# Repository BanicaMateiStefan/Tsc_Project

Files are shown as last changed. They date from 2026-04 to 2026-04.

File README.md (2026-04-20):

# Tsc_Project

## Descriere scurta
    Proiectul are ca obiectiv realizarea designului hardware complet pentru un smartwatch open-source numit InkTime, incluzand schema electrica,PCB-ul, integrarea in carcasa, fisierele de productie si documentatia necesara.

## Diagrama Bloc

Arhitectura hardware este centrata pe microcontrolerul nRF52840, bazat pe ARM Cortex-M4F, care coordoneaza toate perifericele sistemului. Acesta comunica cu:

E-Paper Display-ul, pentru afisarea informatiilor;
accelerometrul BMA423, pentru functii de detectie miscare;
driverul haptic DRV2605, pentru feedback tactil;
cele trei butoane de control: Up, Enter si Down.

Subsistemul de alimentare include:

BQ25180 pentru incarcare LiPo;
RT610A pentru conversie DC/DC;
MAX17048 pentru monitorizarea starii bateriei.

Intrarea de alimentare este realizata prin USB-C, protejata ESD, iar energia este distribuita catre nucleul de procesare si perifericele asociate.
## Diagrama Bloc

```text
+----------------------+
| USB-C Input          |
| + ESD Protection     |
+----------------------+
          |
          v
+----------------------+
| Power Management     |
| BQ25180 + RT610A     |
+----------------------+
          |
          v
+----------------------+
| MAX17048             |
| Fuel Gauge           |
+----------------------+
          |
          v
+----------------------+
| nRF52840 MCU         |
| ARM Cortex-M4F       |
| BLE / GPIO / SPI     |
+----------------------+
      |      |      |
      v      v      v
+---------+ +------+ +------------+
| E-Paper | |BMA423| | DRV2605    |
| Display | |Accel.| | Haptic     |
+---------+ +------+ +------------+
      ^
      |
+----------------------+
| Buttons              |
| Up / Enter / Down    |
+----------------------+
<<<<<<< HEAD
=======
```
## Bill of Materials (BOM)

Lista de materiale se gaseste in fiserul BOM.

Lista scurta cu materialele mai esentiale: 
- U1 - nRF52840 - microcontroller principal cu BLE 5.0 - AQFN
- IC1 - BQ25180 - incarcator Li-Ion / LiPo - DSBGA
- U3 - MAX17048G+T10 - fuel gauge pentru baterie - TDFN
- IC9 - RT6160 - convertor buck-boost - WL-CSP
- IC2 - DRV2605YZFR - driver haptic - BGA
- IC3 - BMA423 - accelerometru - LGA
- ANT1 - 2450AT18B100E - antena 2.45 GHz - chip antenna
- J4 - KH-TYPE-C-16P - conector USB-C
- J1 - 503480-2400 - conector FPC pentru display
- J2 - TC2030 - conector debug/programare
- D3 - USBLC6-2SC6Y - protectie ESD pentru USB
- X1 - 32 MHz crystal - oscilator principal
- X2 - 32.768 kHz crystal - oscilator low power
- SW_UP / SW_ENT / SW_DN - butoane pentru interfata utilizator

## Descriere Hardware

Sistemul hardware este construit in jurul microcontrolerului nRF52840, care reprezinta unitatea principala de procesare si coordoneaza toate modulele periferice. Acesta comunica cu afisajul E-Paper, cu accelerometrul BMA423 pentru detectia miscarii si cu driverul haptic DRV2605 pentru feedback tactil. Alimentarea este gestionata printr-un subsistem dedicat format din incarcatorul BQ25180, circuitul de monitorizare a bateriei MAX17048 si convertorul RT6160, care asigura tensiunile necesare functionarii stabile. Interactiunea cu utilizatorul se realizeaza prin cele trei butoane fizice Up, Enter si Down, iar conectivitatea si depanarea sunt sustinute prin conectorii si test pad-urile integrate pe placa.

## Estimare Consumului de Putere

Consumul de putere este dominat de microcontrolerul nRF52840 in modurile active, in special in timpul comunicatiei BLE, unde valorile tipice sunt de ordinul catorva miliamperi. In modurile low-power, consumul poate cobori la nivel de microamperi, in functie de configurarea sistemului. Circuitele de management energetic, precum MAX17048, BQ25180 si RT6160A, sunt alese pentru aplicatii portabile cu eficienta ridicata, iar perifericele precum DRV2605 si afisajul E-Paper introduc varfuri temporare de consum in timpul vibratiei sau al refresh-ului de ecran. Per ansamblu, sistemul este optimizat pentru autonomie buna, cu consum foarte mic in standby si consum moderat in utilizare activa

| State | Components active | Estimated current |
|---|---|---:|
| Deep sleep | nRF52840 RTC only | ~3 uA |
| BLE advertising | MCU + BLE radio | ~3 mA avg |
| E-paper refresh | MCU + EPD + power stage | ~30 mA peak (1-2 s) |
| IMU active | MCU + BMA423 | ~1.5 mA |
| Haptic feedback | MCU + DRV2605 + actuator | ~10-20 mA peak |
| Full operation (BLE + EPD refresh + IMU) | All | ~35 mA peak |

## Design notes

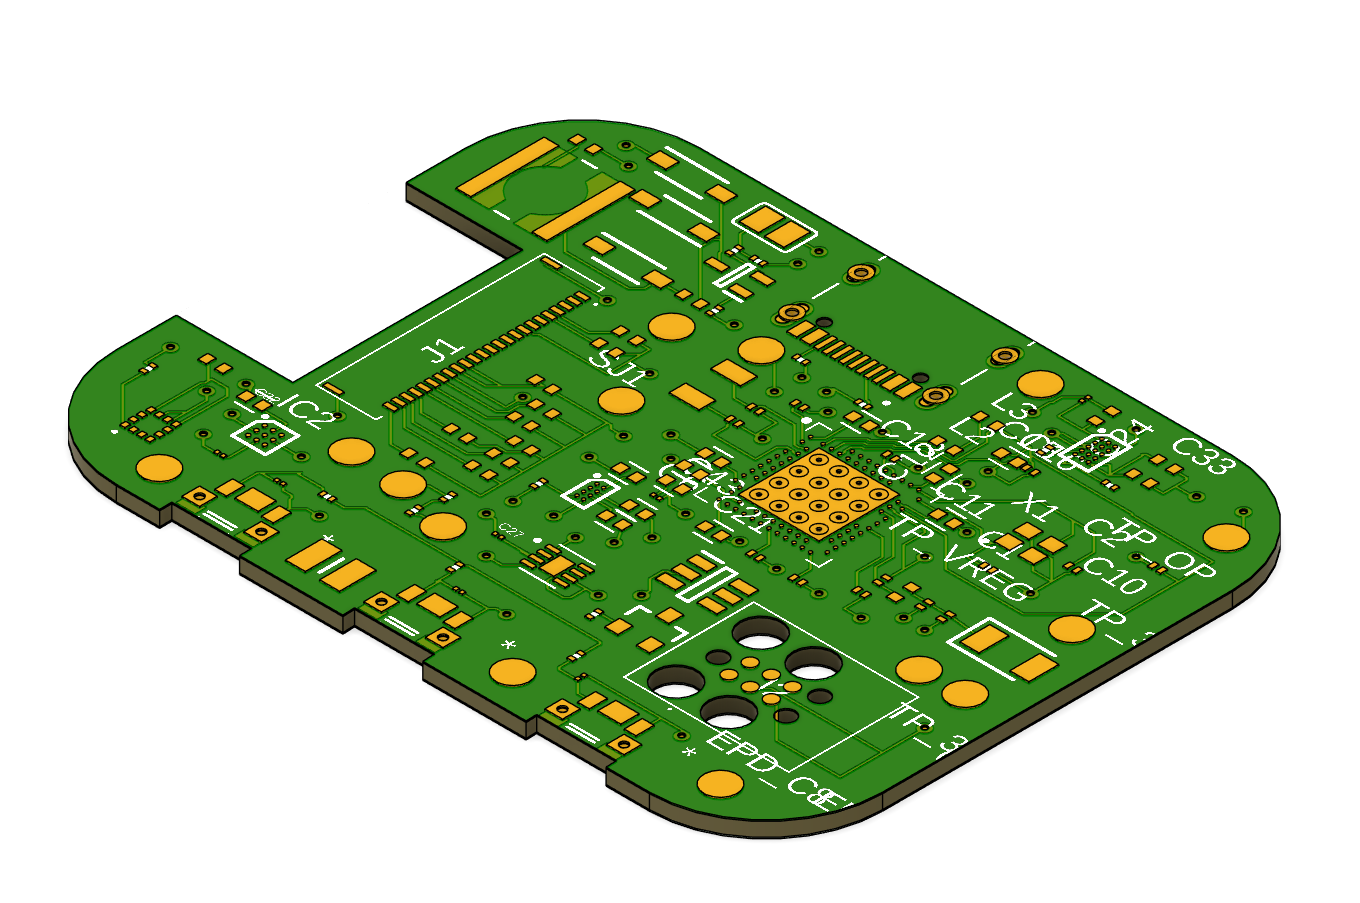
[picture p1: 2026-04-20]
Images/imagine.png

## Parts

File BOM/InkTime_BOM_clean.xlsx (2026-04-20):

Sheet: BOM
Ref | Component | Description | Package | Datasheet
ANT1 | Antenna | Antennas 2.45GHz ANTENNA (JOHANSON TECHNOLOGY 2450AT18B100E) | 2450AT18B100E_ANTC3216X140N
C1 | Capacitor | Generic chip capacitor | NORDIC_NRF_3_RESC0201_L
C1-EP-DR | Capacitor | Generic chip capacitor | NORDIC_NRF_3_RESC0402_L
C2 | Capacitor | Generic chip capacitor | NORDIC_NRF_3_RESC0201_L
C2-EP-DR | Capacitor | Generic chip capacitor | NORDIC_NRF_3_RESC0402_L
C3 | Capacitor | Generic chip capacitor | NORDIC_NRF_3_RESC0201_L
C4 | Capacitor | Generic chip capacitor | NORDIC_NRF_3_RESC0201_L
C5 | Capacitor | Generic chip capacitor | NORDIC_NRF_3_RESC0201_L
C6 | Capacitor | Capacitor - Generic | CAPC1005X60
C7 | Capacitor | Generic chip capacitor | NORDIC_NRF_3_RESC0201_L
C8 | Capacitor | Generic chip capacitor | NORDIC_NRF_3_RESC0201_L
C9 | Capacitor | Generic chip capacitor | NORDIC_NRF_3_RESC0201_L
C10 | Capacitor | Generic chip capacitor | NORDIC_NRF_3_RESC0201_L
C11 | Capacitor | Capacitor - Generic | CAPC1005X60
C12 | Capacitor | Capacitor - Generic | CAPC1005X60
C13 | Capacitor | Generic chip capacitor | NORDIC_NRF_3_RESC0201_L
C14 | Capacitor | Capacitor - Generic | CAPC1005X60
C15 | Capacitor | Capacitor - Generic | CAPC1005X60
C16 | Capacitor | Generic chip capacitor | NORDIC_NRF_3_RESC0201_L
C17 | Capacitor | Generic chip capacitor | NORDIC_NRF_3_RESC0201_L
C18 | Capacitor | Generic chip capacitor | NORDIC_NRF_3_RESC0201_L
C19 | Capacitor | Generic chip capacitor | NORDIC_NRF_3_RESC0402_L
C20 | Capacitor | Capacitor - Generic | CAPC1005X60
C21 | Capacitor | Capacitor - Generic | CAPC1005X60
C22 | Capacitor | Generic chip capacitor | NORDIC_NRF_3_RESC0201_L
C23 | Capacitor | Check availability | GRM011R60J152KE01L_2_CAPC0201X13N | https://www.snapeda.com/parts/GRM011R60J152KE01L/Murata/view-part/?ref=snap
C24 | Capacitor | Generic chip capacitor | NORDIC_NRF_3_RESC0402_L
C25 | Capacitor | Generic chip capacitor | NORDIC_NRF_3_RESC0402_L
C27 | Capacitor | Check availability | GRM011R60J152KE01L_2_CAPC0201X13N | https://www.snapeda.com/parts/GRM011R60J152KE01L/Murata/view-part/?ref=snap
C29 | Capacitor | Check availability | GRM011R60J152KE01L_2_CAPC0201X13N | https://www.snapeda.com/parts/GRM011R60J152KE01L/Murata/view-part/?ref=snap
C30 | Capacitor | Check availability | GRM011R60J152KE01L_2_CAPC0201X13N | https://www.snapeda.com/parts/GRM011R60J152KE01L/Murata/view-part/?ref=snap
C31 | Capacitor | Check availability | GRM011R60J152KE01L_2_CAPC0201X13N | https://www.snapeda.com/parts/GRM011R60J152KE01L/Murata/view-part/?ref=snap
C32 | Capacitor | Capacitor - Generic | CAPC1005X60
C33 | Capacitor | Generic chip capacitor | NORDIC_NRF_3_RESC0402_L
C34 | Capacitor | Check availability | GRM011R60J152KE01L_2_CAPC0201X13N | https://www.snapeda.com/parts/GRM011R60J152KE01L/Murata/view-part/?ref=snap
C37 | Capacitor | Capacitor - Generic | CAPC1005X60
C38 | Capacitor | Capacitor - Generic | CAPC1005X60
C39 | Capacitor | Capacitor - Generic | CAPC1005X60
C42 | Capacitor | Check availability | GRM011R60J152KE01L_2_CAPC0201X13N | https://www.snapeda.com/parts/GRM011R60J152KE01L/Murata/view-part/?ref=snap
C43 | Capacitor | Capacitor - Generic | CAPC1005X60
D2 | Diode / Protection | ON SEMICONDUCTOR - MBR0530 - DIODE, SCHOTTKY, 0.5A, 30V, SOD-123 | ESP32_C6_LIBRARY_5_SOD3716X135N | https://www.snapeda.com/parts/MBR0530/Onsemi/view-part/?ref=snap
D3 | Diode / Protection | Low Cap. ESD Protection Auto SOT-23-6 STMicroelectronics USBLC6-2SC6Y, Dual Uni-Directional TVS Diode Array, 6-Pin SOT-23 | ESP32_C6_LIBRARY_3_SOT95P280X145-6N | https://www.snapeda.com/parts/USBLC6-2SC6Y/STMicroelectronics/view-part/?ref=snap
D4 | Diode / Protection | ON SEMICONDUCTOR - MBR0530 - DIODE, SCHOTTKY, 0.5A, 30V, SOD-123 | ESP32_C6_LIBRARY_5_SOD3716X135N | https://www.snapeda.com/parts/MBR0530/Onsemi/view-part/?ref=snap
D5 | Diode / Protection | ON SEMICONDUCTOR - MBR0530 - DIODE, SCHOTTKY, 0.5A, 30V, SOD-123 | ESP32_C6_LIBRARY_5_SOD3716X135N | https://www.snapeda.com/parts/MBR0530/Onsemi/view-part/?ref=snap
DMG2305UX-7 | Diode / Protection | P-channel MOSFETs | ESP32_C6_LIBRARY_4_ESP32_C6_LIBRARY_4_ESP32_C6_LIBRARY_4_ESP32_C6_LIBRARY_4_ESP32_WROVER_SPARKFUN-DISCRETESEMI_SOT23-3
EPD_C1 | Capacitor | Generic chip capacitor | NORDIC_NRF_3_RESC0402_L
EPD_C2 | Capacitor | Generic chip capacitor | NORDIC_NRF_3_RESC0402_L
EPD_C5 | Capacitor | Generic chip capacitor | NORDIC_NRF_3_RESC0402_L
EPD_C6 | Capacitor | Generic chip capacitor | NORDIC_NRF_3_RESC0402_L
EPD_C7 | Capacitor | Generic chip capacitor | NORDIC_NRF_3_RESC0402_L
EPD_C8 | Capacitor | Generic chip capacitor | NORDIC_NRF_3_RESC0402_L
EPD_C9 | Capacitor | Generic chip capacitor | NORDIC_NRF_3_RESC0402_L
EPD_C10 | Capacitor | Generic chip capacitor | NORDIC_NRF_3_RESC0402_L
EPD_C11 | Capacitor | Generic chip capacitor | NORDIC_NRF_3_RESC0402_L
EPD_C12 | Capacitor | Generic chip capacitor | NORDIC_NRF_3_RESC0402_L
IC1 | IC | BQ25180 - Charger IC Lithium Ion/Polymer, Lithium Iron Phosphate 8-DSBGA (1.6x1.1) | BQ25180YBGR_BGA8C40P2X4_100X155X50
IC2 | IC | DRV2605YZFR - Haptic Driver for ERM/LRA with Built-In Library and Smart Loop Architecture | DRV2605YZFR_BGA9C50P3X3_144X144X62
IC3 | IC | BMA423 - Accelerometers Triaxial low-g 12bit Acceleration Sensor | BMA423_BMA423
IC9 | IC | RT6160 - Buck-Boost Regulator Positive Output Step-Up/Step-Down I2C DC-DC Controller IC 15-WL-CSP (BSC) (1.4x2.3) (RICHTEK RT6160AWSC) | RT6160AWSC_BGA15C40P3X5_140X230X60
J1 | Connector | FFC & FPC Connectors 0.5mm FPC RA SMT Dual Contact 24Ckt (Molex 503480-2400) | 503480-2400_5034802400
J2 | Connector | CABLE ADAPTER 6 POS (Tag Connect TC2030-IDC) | TC2030-IDC_TC2030IDC
J4 | Connector | Check availability | KH-TYPE-C-16P_KINGHELM_KH-TYPE-C-16P | https://www.snapeda.com/parts/KH-TYPE-C-16P/Kinghelm/view-part/?ref=snap
L1 | Inductor | Generic chip inductor | NORDIC_NRF_2_RESC0402_L
L2 | Inductor | Generic chip inductor | NORDIC_NRF_2_RESC0402_L
L3 | Inductor | Generic chip inductor | NORDIC_NRF_2_RESC0402_L
L5 | Inductor | Inductor 68uH | ESP32_C6_LIBRARY_2_IND_4828-WE-TPC_WRE
L7 | Inductor | SMD / SMT Inductors (Coils), L=0.47?H, L x W x T : | MLP2016SR47MT0S1_INDC2016X100N
Q3 | Transistor / MOSFET | MOSFET N-Ch 30V 1.5A TrenchFET SC70 Vishay Si1308EDL-T1-GE3 N-channel MOSFET Transistor, 1.5 A, 30 V, 3-Pin SC-70 | ESP32_C6_LIBRARY_6_SOT65P210X110-3N
R1_EP_DR1 | Resistor | 7.68k 0201 Thin Film Surface Mount Fixed Resistor +/-0.5% 0.031W CPF0201D7K68C1 | CPF0201D7K68C1_0201
R1_USB | Resistor | 7.68k 0201 Thin Film Surface Mount Fixed Resistor +/-0.5% 0.031W CPF0201D7K68C1 | CPF0201D7K68C1_0201
R2 | Resistor | 7.68k 0201 Thin Film Surface Mount Fixed Resistor +/-0.5% 0.031W CPF0201D7K68C1 | CPF0201D7K68C1_0201
R2_EP_DR | Resistor | 7.68k 0201 Thin Film Surface Mount Fixed Resistor +/-0.5% 0.031W CPF0201D7K68C1 | CPF0201D7K68C1_0201
R2_USB | Resistor | 7.68k 0201 Thin Film Surface Mount Fixed Resistor +/-0.5% 0.031W CPF0201D7K68C1 | CPF0201D7K68C1_0201
R3 | Resistor | 7.68k 0201 Thin Film Surface Mount Fixed Resistor +/-0.5% 0.031W CPF0201D7K68C1 | CPF0201D7K68C1_0201
R4 | Resistor | 7.68k 0201 Thin Film Surface Mount Fixed Resistor +/-0.5% 0.031W CPF0201D7K68C1 | CPF0201D7K68C1_0201
R5 | Resistor | 7.68k 0201 Thin Film Surface Mount Fixed Resistor +/-0.5% 0.031W CPF0201D7K68C1 | CPF0201D7K68C1_0201
R7 | Resistor | 7.68k 0201 Thin Film Surface Mount Fixed Resistor +/-0.5% 0.031W CPF0201D7K68C1 | CPF0201D7K68C1_0201
R8 | Resistor | 7.68k 0201 Thin Film Surface Mount Fixed Resistor +/-0.5% 0.031W CPF0201D7K68C1 | CPF0201D7K68C1_0201
R9 | Resistor | 7.68k 0201 Thin Film Surface Mount Fixed Resistor +/-0.5% 0.031W CPF0201D7K68C1 | CPF0201D7K68C1_0201
R17 | Resistor | 7.68k 0201 Thin Film Surface Mount Fixed Resistor +/-0.5% 0.031W CPF0201D7K68C1 | CPF0201D7K68C1_0201
R18 | Resistor | 7.68k 0201 Thin Film Surface Mount Fixed Resistor +/-0.5% 0.031W CPF0201D7K68C1 | CPF0201D7K68C1_0201
R_PWR_EPD | Resistor | 7.68k 0201 Thin Film Surface Mount Fixed Resistor +/-0.5% 0.031W CPF0201D7K68C1 | CPF0201D7K68C1_0201
R_TYPE_SEL | Resistor | 7.68k 0201 Thin Film Surface Mount Fixed Resistor +/-0.5% 0.031W CPF0201D7K68C1 | CPF0201D7K68C1_0201
SJ1 | Solder Jumper | SMD solder JUMPER | ESP32_C6_LIBRARY_7_JUMPER_SJ
SW_DN | Switch | Tactile switch (Panasonic EVP-AKE31A) | 2025-10-22_07-23-44_LIBRARY_SW_EVP-AKE31A_PAN
SW_ENT | Switch | Tactile switch (Panasonic EVP-AKE31A) | 2025-10-22_07-23-44_LIBRARY_SW_EVP-AKE31A_PAN
SW_UP | Switch | Tactile switch (Panasonic EVP-AKE31A) | 2025-10-22_07-23-44_LIBRARY_SW_EVP-AKE31A_PAN
TP_3.3V | Test Pad | Test pad | HECTOR_WATCH_1_TP20R
TP_3V3 | Test Pad | Test pad | HECTOR_WATCH_1_TP20R
TP_BAT_GND | Test Pad | Test pad | HECTOR_WATCH_1_TP20R
TP_GND | Test Pad | Test pad | HECTOR_WATCH_1_TP20R
TP_ON | Test Pad | Test pad | HECTOR_WATCH_1_TP20R
TP_OP | Test Pad | Test pad | HECTOR_WATCH_1_TP20R
TP_RESET | Test Pad | Test pad | HECTOR_WATCH_1_TP20R
TP_SCL | Test Pad | Test pad | HECTOR_WATCH_1_TP20R
TP_SDA | Test Pad | Test pad | HECTOR_WATCH_1_TP20R
TP_SWDCLK | Test Pad | Test pad | HECTOR_WATCH_1_TP20R
TP_SWDIO | Test Pad | Test pad | HECTOR_WATCH_1_TP20R
TP_SWO | Test Pad | Test pad | HECTOR_WATCH_1_TP20R
TP_VBAT | Test Pad | Test pad | HECTOR_WATCH_1_TP20R
TP_VREG | Test Pad | Test pad | HECTOR_WATCH_1_TP20R
U1 | IC | nRF52840 | NORDIC_NRF_4_AQFN50P700X700X85_HS-74N
U3 | IC | MAX17048G+T10 - Check availability | ESP32_C6_LIBRARY_SON50P200X200X80-9N | https://www.snapeda.com/parts/MAX17048G+T10/Analog+Devices/view-part/?ref=snap
X1 | Crystal | Crystal 32MHZ | NORDIC_NRF_BT-XTAL_2016_N
X2 | Crystal | Crystal 32.768kHz | NORDIC_NRF_1_XTAL_3215_N

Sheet: Notes
Note | Details
Source | Built from the BOM text and placement text provided in chat.
Datasheet field | Where a datasheet URL was missing in the source, the cell is left blank.
Package field | Taken primarily from the placement/package mapping you pasted.
Descriptions | Auto-cleaned from source descriptions; some generic parts keep generic descriptions.
Potential issue | Some entries from the original CSV look inconsistent, especially a few Murata capacitor rows and placeholder 'Check availability' descriptions.
Potential issue | Several generic parts from Nordic libraries do not include manufacturer-specific datasheet links in the provided source.
Potential issue | If you want, this can be refined into a production-ready BOM with manufacturer, MPN, quantity, and supplier links.

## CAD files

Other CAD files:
Mechanical/Matei_TSC_1.f3d

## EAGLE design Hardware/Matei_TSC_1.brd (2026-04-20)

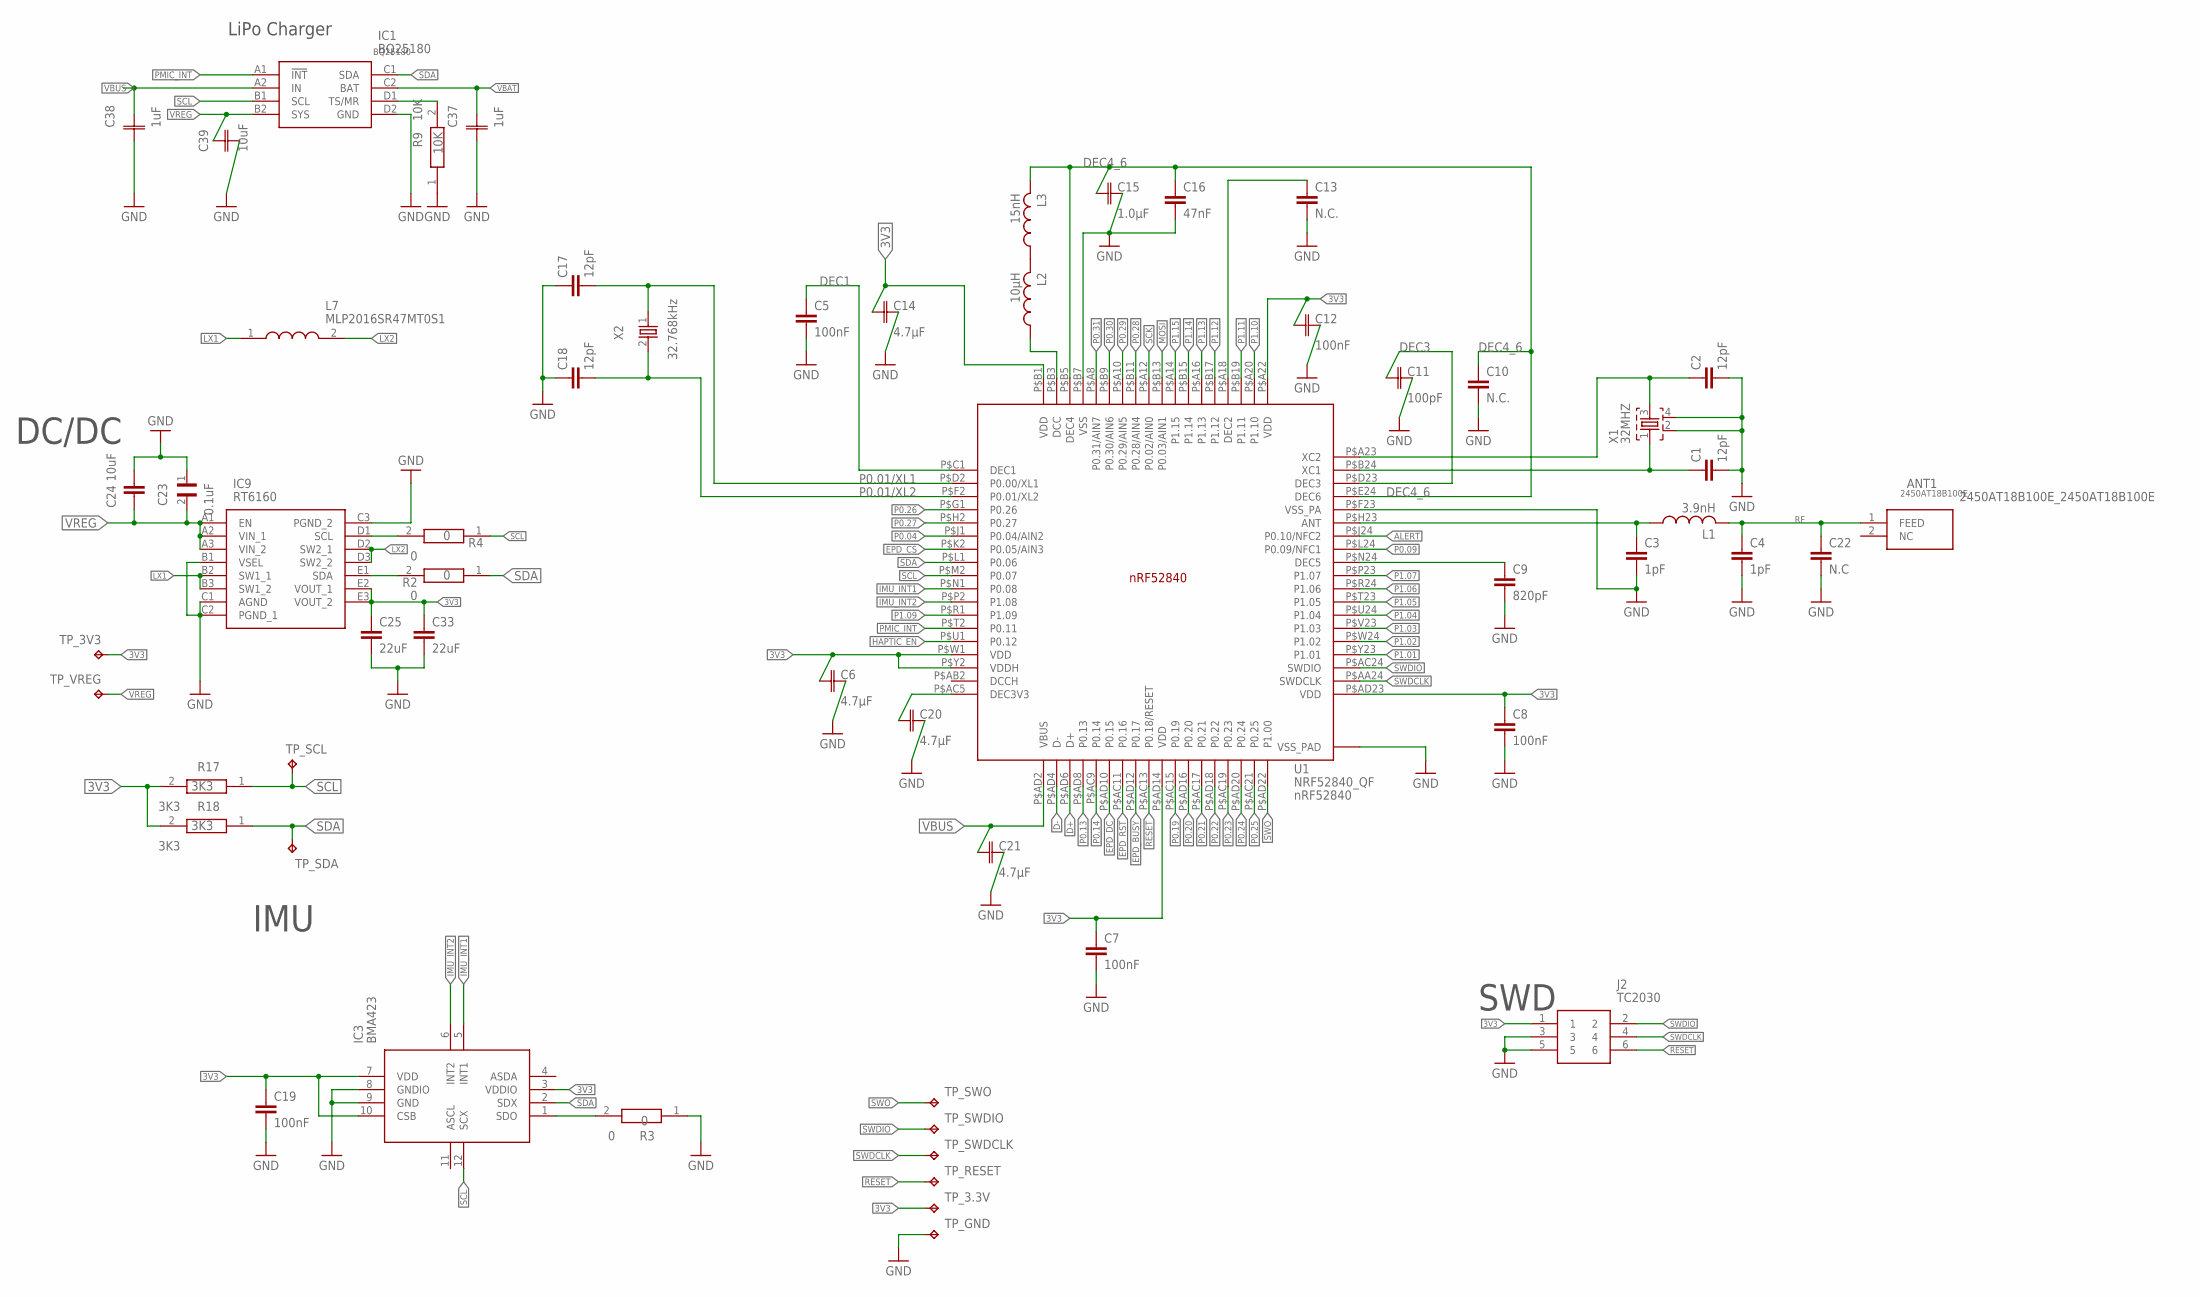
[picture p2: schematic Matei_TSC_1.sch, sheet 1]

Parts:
ANT1: 2450AT18B100E_2450AT18B100E; 2450AT18B100E_ANTC3216X140N
C1, C2, C17, C18: 12pF; NORDIC_NRF_3_RESC0201_L
C3, C4: 1pF; NORDIC_NRF_3_RESC0201_L
C5, C7, C8: 100nF; NORDIC_NRF_3_RESC0201_L
C6, C14, C20, C21: 4.7µF; CAPC1005X60
C9: 820pF; NORDIC_NRF_3_RESC0201_L
C10, C13: N.C.; NORDIC_NRF_3_RESC0201_L
C11: 100pF; CAPC1005X60
C12: 100nF; CAPC1005X60
C15: 1.0µF; CAPC1005X60
C16: 47nF; NORDIC_NRF_3_RESC0201_L
C19: 100nF; NORDIC_NRF_3_RESC0402_L
C22: N.C; NORDIC_NRF_3_RESC0201_L
C23: 0.1uF; GRM011R60J152KE01L_2_CAPC0201X13N
C24: 10uF; NORDIC_NRF_3_RESC0402_L
C25, C33: 22uF; NORDIC_NRF_3_RESC0402_L
C37, C38: 1uF; CAPC1005X60
C39: 10uF; CAPC1005X60
IC1: BQ25180; BQ25180YBGR_BGA8C40P2X4_100X155X50
IC3: BMA423; BMA423_BMA423
IC9: RT6160; RT6160AWSC_BGA15C40P3X5_140X230X60
J2: TC2030; TC2030-IDC_TC2030IDC
L1: 3.9nH; NORDIC_NRF_2_RESC0402_L
L2: 10µH; NORDIC_NRF_2_RESC0402_L
L3: 15nH; NORDIC_NRF_2_RESC0402_L
L7: MLP2016SR47MT0S1; MLP2016SR47MT0S1_INDC2016X100N
R2, R3, R4: 0; CPF0201D7K68C1_0201
R9: 10K; CPF0201D7K68C1_0201
R17, R18: 3K3; CPF0201D7K68C1_0201
TP_3.3V, TP_3V3: HECTOR_WATCH_1_TPTP20R; HECTOR_WATCH_1_TP20R
TP_GND: HECTOR_WATCH_1_TPTP20R; HECTOR_WATCH_1_TP20R
TP_RESET: HECTOR_WATCH_1_TPTP20R; HECTOR_WATCH_1_TP20R
TP_SCL: HECTOR_WATCH_1_TPTP20R; HECTOR_WATCH_1_TP20R
TP_SDA: HECTOR_WATCH_1_TPTP20R; HECTOR_WATCH_1_TP20R
TP_SWDCLK: HECTOR_WATCH_1_TPTP20R; HECTOR_WATCH_1_TP20R
TP_SWDIO: HECTOR_WATCH_1_TPTP20R; HECTOR_WATCH_1_TP20R
TP_SWO: HECTOR_WATCH_1_TPTP20R; HECTOR_WATCH_1_TP20R
TP_VREG: HECTOR_WATCH_1_TPTP20R; HECTOR_WATCH_1_TP20R
U1: nRF52840; NORDIC_NRF_4_AQFN50P700X700X85_HS-74N
X1: 32MHZ; NORDIC_NRF_BT-XTAL_2016_N
X2: 32.768kHz; NORDIC_NRF_1_XTAL_3215_N

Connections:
3V3: C6.1, C7.1, C8.1, C12.1, C14.1, C19.1, C25.1, C33.1, IC3.3 (VDDIO), IC3.7 (VDD), IC3.10 (CSB), IC9.E2 (VOUT_1), IC9.E3 (VOUT_2), J2.1, R17.2, R18.2, TP_3.3V.TP, TP_3V3.TP, U1.P$A22 (VDD), U1.P$AD14 (VDD), U1.P$AD23 (VDD), U1.P$B1 (VDD), U1.P$W1 (VDD), U1.P$Y2 (VDDH); also elsewhere on the board
ALERT: U1.P$J24 (P0.10/NFC2); also elsewhere on the board
D+: U1.P$AD6 (D+); also elsewhere on the board
D-: U1.P$AD4 (D-); also elsewhere on the board
DEC1: C5.1, U1.P$C1 (DEC1)
DEC3: C11.1, U1.P$D23 (DEC3)
DEC4_6: C10.1, C15.1, C16.1, L3.2, U1.P$B5 (DEC4), U1.P$E24 (DEC6)
EPD_BUSY: U1.P$AD12 (P0.17); also elsewhere on the board
EPD_CS: U1.P$K2 (P0.05/AIN3); also elsewhere on the board
EPD_DC: U1.P$AD10 (P0.15); also elsewhere on the board
EPD_RST: U1.P$AC11 (P0.16); also elsewhere on the board
GND: C1.2, C2.2, C3.2, C4.2, C5.2, C6.2, C7.2, C8.2, C9.2, C10.2, C11.2, C12.2, C13.2, C14.2, C15.2, C16.2, C17.1, C18.1, C19.2, C20.2, C21.2, C22.2, C23.1, C24.1, C25.2, C33.2, C37.1, C38.1, C39.2, IC1.D2 (GND), IC3.8 (GNDIO), IC3.9 (GND), IC9.B1 (VSEL), IC9.C1 (AGND), IC9.C2 (PGND_1), IC9.C3 (PGND_2), J2.3, J2.5, R3.1, R9.1, TP_GND.TP, U1.P$74 (VSS_PAD), U1.P$75 (VSS_PAD), U1.P$76 (VSS_PAD), U1.P$77 (VSS_PAD), U1.P$78 (VSS_PAD), U1.P$79 (VSS_PAD), U1.P$80 (VSS_PAD), U1.P$81 (VSS_PAD), U1.P$82 (VSS_PAD), U1.P$83 (VSS_PAD), U1.P$84 (VSS_PAD), U1.P$85 (VSS_PAD), U1.P$86 (VSS_PAD), U1.P$87 (VSS_PAD), U1.P$88 (VSS_PAD), U1.P$89 (VSS_PAD), U1.P$90 (VSS_PAD), U1.P$B7 (VSS), U1.P$F23 (VSS_PA), X1.2, X1.4; also elsewhere on the board
HAPTIC_EN: U1.P$U1 (P0.12); also elsewhere on the board
IMU_INT1: IC3.5 (INT1), U1.P$N1 (P0.08)
IMU_INT2: IC3.6 (INT2), U1.P$P2 (P1.08)
LX1: IC9.B2 (SW1_1), IC9.B3 (SW1_2), L7.1
LX2: IC9.D2 (SW2_1), IC9.D3 (SW2_2), L7.2
MOSI: U1.P$B13 (P0.03/AIN1); also elsewhere on the board
unnamed: C20.1, U1.P$AC5 (DEC3V3)
unnamed: C9.1, U1.P$N24 (DEC5)
unnamed: C3.1, L1.1, U1.P$H23 (ANT)
unnamed: C1.1, U1.P$B24 (XC1), X1.1
unnamed: C2.1, U1.P$A23 (XC2), X1.3
unnamed: L2.1, U1.P$B3 (DCC)
unnamed: L2.2, L3.1
unnamed: C13.1, U1.P$A18 (DEC2)
unnamed: IC1.D1 (TS/MR), R9.2
unnamed: IC9.D1 (SCL), R4.2
unnamed: IC9.E1 (SDA), R2.2
unnamed: IC3.1 (SDO), R3.2
P0.01/XL1: C17.2, U1.P$D2 (P0.00/XL1), X2.1
P0.01/XL2: C18.2, U1.P$F2 (P0.01/XL2), X2.2
P0.04: U1.P$J1 (P0.04/AIN2)
P0.09: U1.P$L24 (P0.09/NFC1)
P0.13: U1.P$AD8 (P0.13); also elsewhere on the board
P0.14: U1.P$AC9 (P0.14); also elsewhere on the board
P0.19: U1.P$AC15 (P0.19)
P0.20: U1.P$AD16 (P0.20)
P0.21: U1.P$AC17 (P0.21)
P0.22: U1.P$AD18 (P0.22)
P0.23: U1.P$AC19 (P0.23)
P0.24: U1.P$AD20 (P0.24)
P0.25: U1.P$AC21 (P0.25)
P0.26: U1.P$G1 (P0.26)
P0.27: U1.P$H2 (P0.27)
P0.28: U1.P$B11 (P0.28/AIN4)
P0.29: U1.P$A10 (P0.29/AIN5)
P0.30: U1.P$B9 (P0.30/AIN6)
P0.31: U1.P$A8 (P0.31/AIN7)
P1.01: U1.P$Y23 (P1.01); also elsewhere on the board
P1.02: U1.P$W24 (P1.02); also elsewhere on the board
P1.03: U1.P$V23 (P1.03)
P1.04: U1.P$U24 (P1.04)
P1.05: U1.P$T23 (P1.05)
P1.06: U1.P$R24 (P1.06)
P1.07: U1.P$P23 (P1.07)
P1.09: U1.P$R1 (P1.09)
P1.10: U1.P$A20 (P1.10)
P1.11: U1.P$B19 (P1.11)
P1.12: U1.P$B17 (P1.12)
P1.13: U1.P$A16 (P1.13)
P1.14: U1.P$B15 (P1.14)
P1.15: U1.P$A14 (P1.15)
PMIC_INT: IC1.A1 (!INT), U1.P$T2 (P0.11)
RESET: J2.6, TP_RESET.TP, U1.P$AC13 (P0.18/RESET)
RF: ANT1.1 (FEED), C4.1, C22.1, L1.2
SCK: U1.P$A12 (P0.02/AIN0); also elsewhere on the board
SCL: IC1.B1 (SCL), IC3.12 (SCX), R4.1, R17.1, TP_SCL.TP, U1.P$M2 (P0.07); also elsewhere on the board
SDA: IC1.C1 (SDA), IC3.2 (SDX), R2.1, R18.1, TP_SDA.TP, U1.P$L1 (P0.06); also elsewhere on the board
SWDCLK: J2.4, TP_SWDCLK.TP, U1.P$AA24 (SWDCLK)
SWDIO: J2.2, TP_SWDIO.TP, U1.P$AC24 (SWDIO)
SWO: TP_SWO.TP, U1.P$AD22 (P1.00)
VBAT: C37.2, IC1.C2 (BAT); also elsewhere on the board
VBUS: C21.1, C38.2, IC1.A2 (IN), U1.P$AD2 (VBUS); also elsewhere on the board
VREG: C23.2, C24.2, C39.1, IC1.B2 (SYS), IC9.A1 (EN), IC9.A2 (VIN_1), IC9.A3 (VIN_2), TP_VREG.TP

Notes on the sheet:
LiPo Charger
DC/DC
IMU
SWD

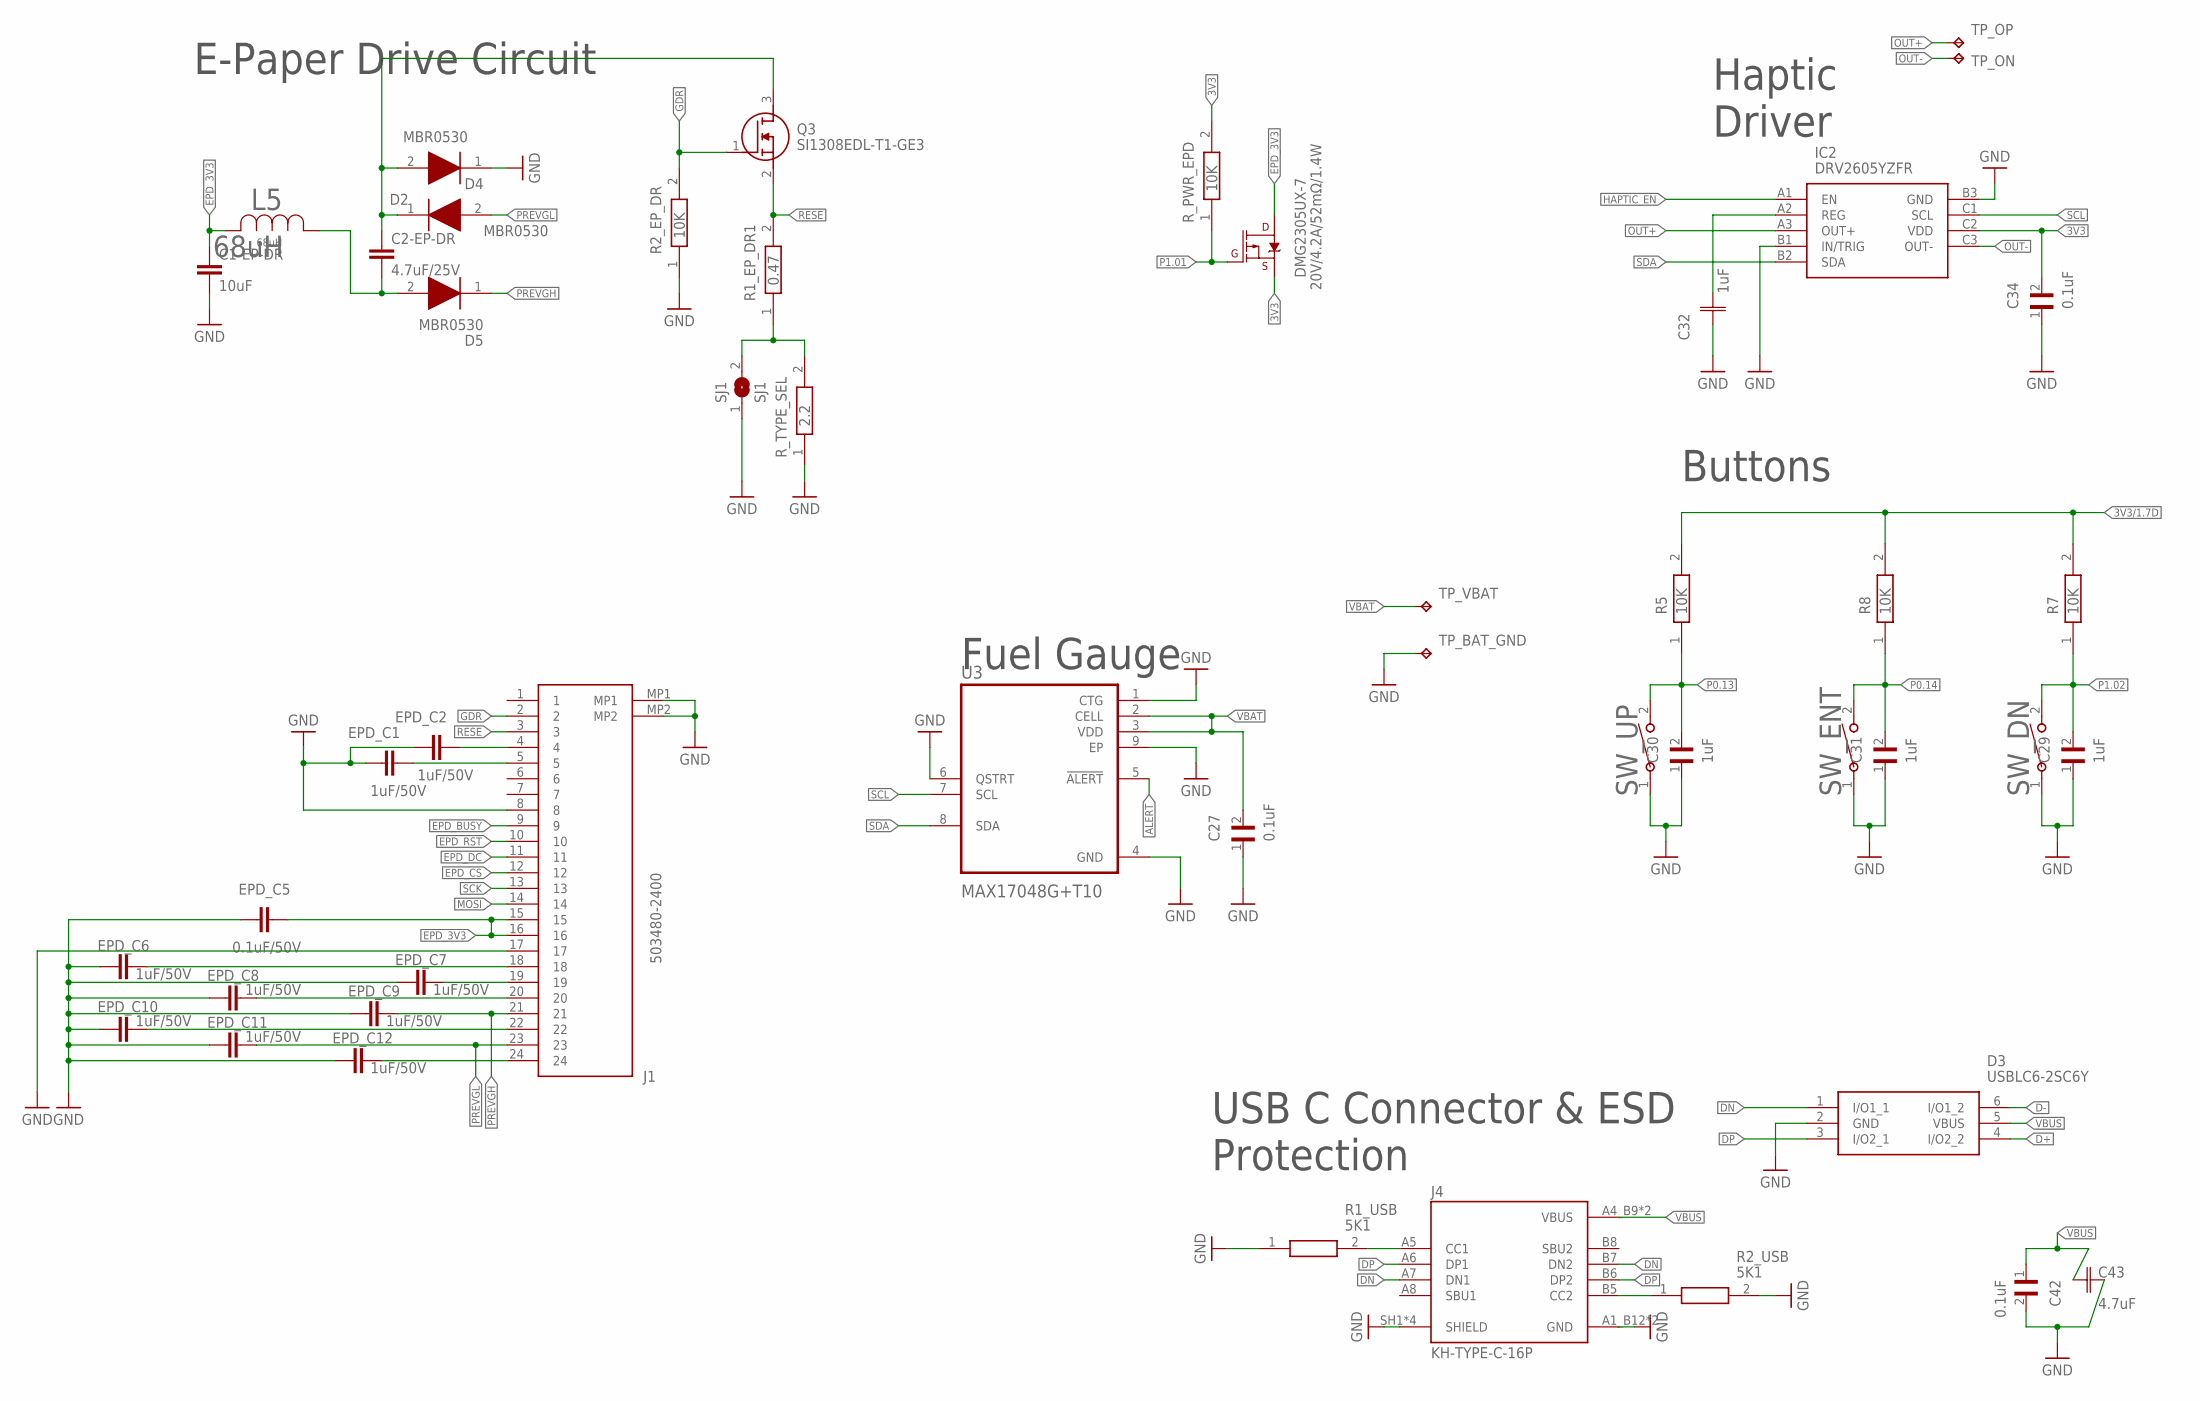
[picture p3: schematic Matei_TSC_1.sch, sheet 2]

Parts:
C1-EP-DR: 10uF; NORDIC_NRF_3_RESC0402_L
C2-EP-DR: 4.7uF/25V; NORDIC_NRF_3_RESC0402_L
C27, C34, C42: 0.1uF; GRM011R60J152KE01L_2_CAPC0201X13N
C29, C30, C31: 1uF; GRM011R60J152KE01L_2_CAPC0201X13N
C32: 1uF; CAPC1005X60
C43: 4.7uF; CAPC1005X60
D2, D4, D5: MBR0530; ESP32_C6_LIBRARY_5_SOD3716X135N
D3: USBLC6-2SC6Y; ESP32_C6_LIBRARY_3_SOT95P280X145-6N
DMG2305UX-7: 20V/4.2A/52mΩ/1.4W; ESP32_C6_LIBRARY_4_ESP32_C6_LIBRARY_4_ESP32_C6_LIBRARY_4_ES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
EPD_C1, EPD_C2, EPD_C6, EPD_C7, EPD_C8, EPD_C9, EPD_C10, EPD_C11, EPD_C12: 1uF/50V; NORDIC_NRF_3_RESC0402_L
EPD_C5: 0.1uF/50V; NORDIC_NRF_3_RESC0402_L
IC2: DRV2605YZFR; DRV2605YZFR_BGA9C50P3X3_144X144X62
J1: 503480-2400; 503480-2400_5034802400
J4: KH-TYPE-C-16P; KH-TYPE-C-16P_KINGHELM_KH-TYPE-C-16P
L5: 68uH; ESP32_C6_LIBRARY_2_IND_4828-WE-TPC_WRE
Q3: SI1308EDL-T1-GE3; ESP32_C6_LIBRARY_6_SOT65P210X110-3N
R1_EP_DR1: 0.47; CPF0201D7K68C1_0201
R1_USB, R2_USB: 5K1; CPF0201D7K68C1_0201
R2_EP_DR, R5, R7, R8: 10K; CPF0201D7K68C1_0201
R_PWR_EPD: 10K; CPF0201D7K68C1_0201
R_TYPE_SEL: 2.2; CPF0201D7K68C1_0201
SJ1: SJ1; ESP32_C6_LIBRARY_7_JUMPER_SJ
SW_DN: 2025-10-22_07-23-44_LIBRARY_EVP-AKE31ASW_EVP-AKE3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; 2025-10-22_07-23-44_LIBRARY_SW_EVP-AKE31A_PAN
SW_ENT: 2025-10-22_07-23-44_LIBRARY_EVP-AKE31ASW_EVP-AKE3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; 2025-10-22_07-23-44_LIBRARY_SW_EVP-AKE31A_PAN
SW_UP: 2025-10-22_07-23-44_LIBRARY_EVP-AKE31ASW_EVP-AKE3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; 2025-10-22_07-23-44_LIBRARY_SW_EVP-AKE31A_PAN
TP_BAT_GND: HECTOR_WATCH_1_TPTP20R; HECTOR_WATCH_1_TP20R
TP_ON: HECTOR_WATCH_1_TPTP20R; HECTOR_WATCH_1_TP20R
TP_OP: HECTOR_WATCH_1_TPTP20R; HECTOR_WATCH_1_TP20R
TP_VBAT: HECTOR_WATCH_1_TPTP20R; HECTOR_WATCH_1_TP20R
U3: MAX17048G+T10; ESP32_C6_LIBRARY_SON50P200X200X80-9N

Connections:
3V3: C34.2, DMG2305UX-7.2 (S), IC2.C2 (VDD), R_PWR_EPD.2; also elsewhere on the board
3V3/1.7D: R5.2, R7.2, R8.2
ALERT: U3.5 (!ALERT); also elsewhere on the board
D+: D3.4 (I/O2_2); also elsewhere on the board
D-: D3.6 (I/O1_2); also elsewhere on the board
DN: D3.1 (I/O1_1), J4.A7 (DN1), J4.B7 (DN2)
DP: D3.3 (I/O2_1), J4.A6 (DP1), J4.B6 (DP2)
EPD_3V3: C1-EP-DR.1, DMG2305UX-7.3 (D), EPD_C5.2, J1.15, J1.16, L5.2
EPD_BUSY: J1.9; also elsewhere on the board
EPD_CS: J1.12; also elsewhere on the board
EPD_DC: J1.11; also elsewhere on the board
EPD_RST: J1.10; also elsewhere on the board
GDR: J1.2, Q3.1 (G), R2_EP_DR.2
GND: C1-EP-DR.2, C27.1, C29.1, C30.1, C31.1, C32.1, C34.1, C42.2, C43.2, D3.2 (GND), D4.1 (K), EPD_C1.1, EPD_C2.1, EPD_C5.1, EPD_C6.1, EPD_C7.1, EPD_C8.1, EPD_C9.1, EPD_C10.1, EPD_C11.1, EPD_C12.1, IC2.B1 (IN/TRIG), IC2.B3 (GND), J1.8, J1.17, J1.MP1, J1.MP2, J4.A1_B12 (GND), J4.A12_B1 (GND), J4.SH1 (SHIELD), J4.SH2 (SHIELD), J4.SH3 (SHIELD), J4.SH4 (SHIELD), R1_USB.1, R2_EP_DR.1, R2_USB.2, R_TYPE_SEL.1, SJ1.1, SW_DN.1, SW_ENT.1, SW_UP.1, TP_BAT_GND.TP, U3.1 (CTG), U3.4 (GND), U3.6 (QSTRT), U3.9 (EP); also elsewhere on the board
HAPTIC_EN: IC2.A1 (EN); also elsewhere on the board
MOSI: J1.14; also elsewhere on the board
unnamed: C2-EP-DR.2, D5.2 (A), L5.1
unnamed: C2-EP-DR.1, D2.1 (K), D4.2 (A), Q3.3 (D)
unnamed: R1_EP_DR1.1, R_TYPE_SEL.2, SJ1.2
unnamed: C32.2, IC2.A2 (REG)
unnamed: J4.A5 (CC1), R1_USB.2
unnamed: EPD_C2.2, J1.4
unnamed: J4.B5 (CC2), R2_USB.1
unnamed: EPD_C1.2, J1.5
unnamed: EPD_C6.2, J1.18
unnamed: EPD_C7.2, J1.19
unnamed: EPD_C8.2, J1.20
unnamed: EPD_C10.2, J1.22
unnamed: EPD_C12.2, J1.24
OUT+: IC2.A3 (OUT+), TP_OP.TP
OUT-: IC2.C3 (OUT-), TP_ON.TP
P0.13: C30.2, R5.1, SW_UP.2; also elsewhere on the board
P0.14: C31.2, R8.1, SW_ENT.2; also elsewhere on the board
P1.01: DMG2305UX-7.1 (G), R_PWR_EPD.1; also elsewhere on the board
P1.02: C29.2, R7.1, SW_DN.2; also elsewhere on the board
PREVGH: D5.1 (K), EPD_C9.2, J1.21
PREVGL: D2.2 (A), EPD_C11.2, J1.23
RESE: J1.3, Q3.2 (S), R1_EP_DR1.2
SCK: J1.13; also elsewhere on the board
SCL: IC2.C1 (SCL), U3.7 (SCL); also elsewhere on the board
SDA: IC2.B2 (SDA), U3.8 (SDA); also elsewhere on the board
VBAT: C27.2, TP_VBAT.TP, U3.2 (CELL), U3.3 (VDD); also elsewhere on the board
VBUS: C42.1, C43.1, D3.5 (VBUS), J4.A4_B9 (VBUS), J4.A9_B4 (VBUS); also elsewhere on the board

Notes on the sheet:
E-Paper Drive Circuit
Haptic Driver
Buttons
Fuel Gauge
USB C Connector & ESD Protection

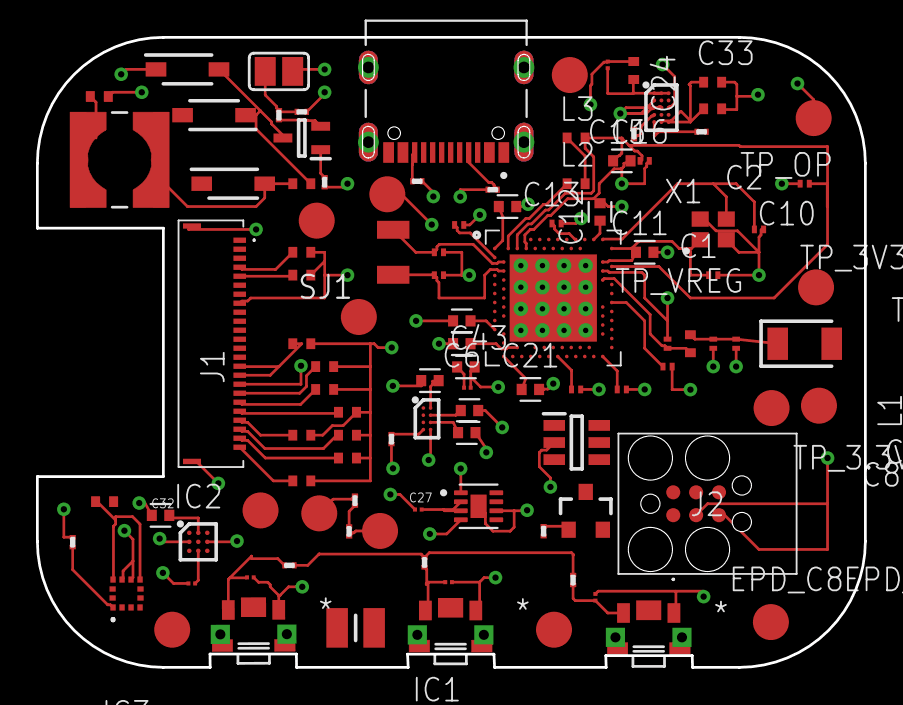
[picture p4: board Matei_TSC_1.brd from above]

Board: 4 copper layers, 46.0 x 35.0 mm, 105 parts (0 on the bottom side), 71 nets.

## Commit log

2026-04-20 Update README with essential materials list
    Added a list of essential materials for the project.
2026-04-20 Add power consumption estimation to README
    Added power consumption estimation section with details on current usage for various states.

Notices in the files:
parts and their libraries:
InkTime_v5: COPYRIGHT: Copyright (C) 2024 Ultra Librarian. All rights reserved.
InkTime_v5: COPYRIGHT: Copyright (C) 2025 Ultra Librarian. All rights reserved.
